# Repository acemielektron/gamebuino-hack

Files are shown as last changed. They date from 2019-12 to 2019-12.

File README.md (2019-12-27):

# gamebuino-hack
A diy clone of open source [gamebuino classic](http://legacy.gamebuino.com/wiki)

**Differences in hardware**
  - Hack is based on Atmega328 PDIP so it does not have A6 and A7 (PC6 and PC7) pins
  - Button C is moved to D5 (PD5) -> rebuilding all games and bootloader needed for this change to work
  - Battery sensor is moved to ADC3 (PC3) -> rebuilding all games are needed for this change to work
  - No ambient light sensor
  - No pwm control for background led

**Bootloader**
  - gamebuino requires a [custom bootloader](https://github.com/ghalfacree/Arduino-Sketches/tree/master/hardware/arduino/bootloaders/gamebuino_boot) for loading games from sd-card to work
  - gamebuino bootloader only supports fat16 formatted sd cards

**Pictures**

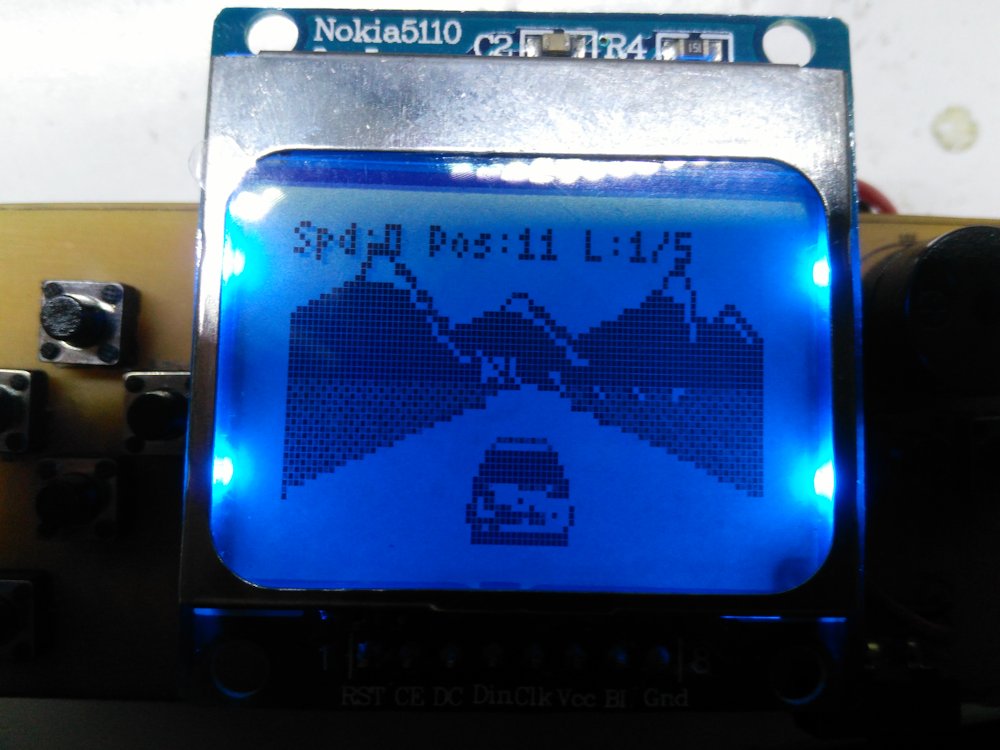
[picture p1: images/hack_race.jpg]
Hack running race


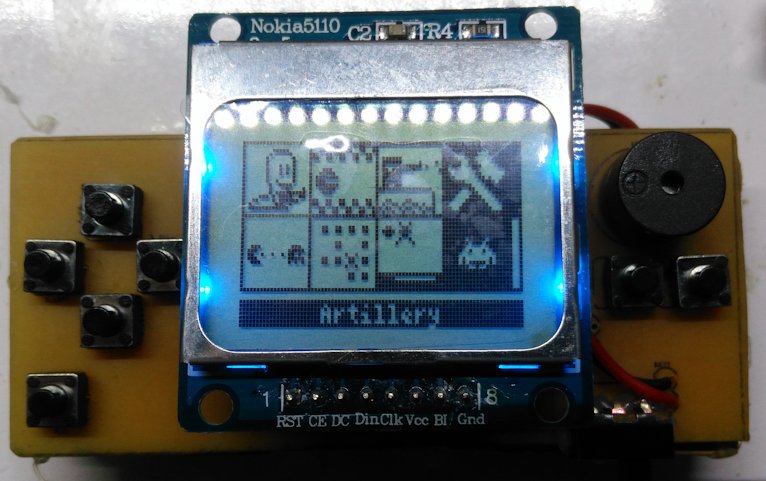
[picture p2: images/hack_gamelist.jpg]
Hack games selection screen


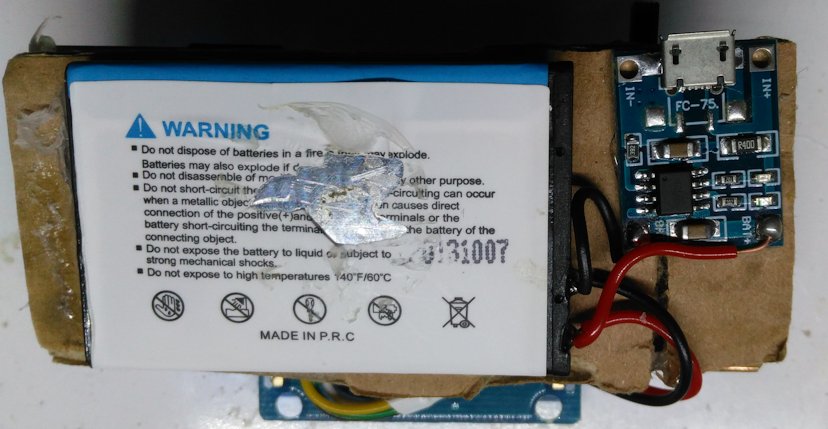
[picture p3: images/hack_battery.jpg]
Hack 850ma Nokia battery & TP4056 charger


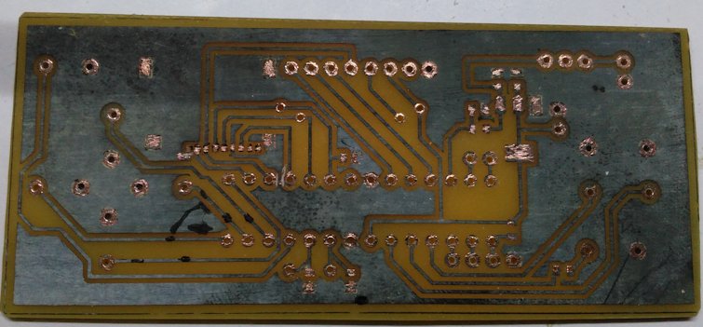
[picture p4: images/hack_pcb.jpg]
Hack PCB backside


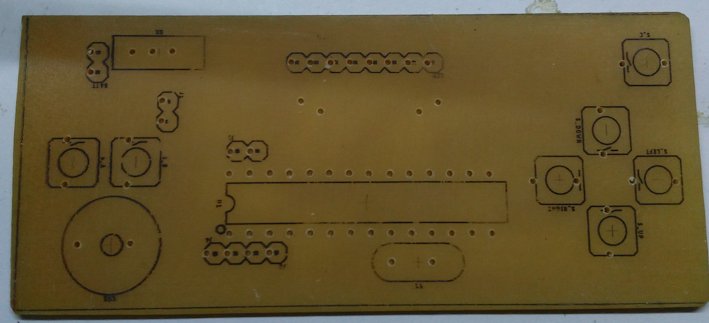
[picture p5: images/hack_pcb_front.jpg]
Hack PCB frontside


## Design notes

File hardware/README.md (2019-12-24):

# gamebuino-hack (eagle cad files)
A diy clone of open source [gamebuino classic](http://legacy.gamebuino.com/wiki)

**Differences in hardware**
  - Hack is based on Atmega328 PDIP so it does not have A6 and A7 (PC6 and PC7) pins
  - Button C is moved to D5 (PD5) -> rebuilding all games and bootloader needed for this change to work
  - Battery sensor is moved to ADC3 (PC3) -> rebuilding all games are needed for this change to work
  - No ambient light sensor
  - No pwm control for background led

**Bootloader**
  - gamebuino requires a [custom bootloader](https://github.com/ghalfacree/Arduino-Sketches/tree/master/hardware/arduino/bootloaders/gamebuino_boot) for loading games from sd-card to work
  - gamebuino bootloader only supports fat16 formatted sd cards

**Schematic**
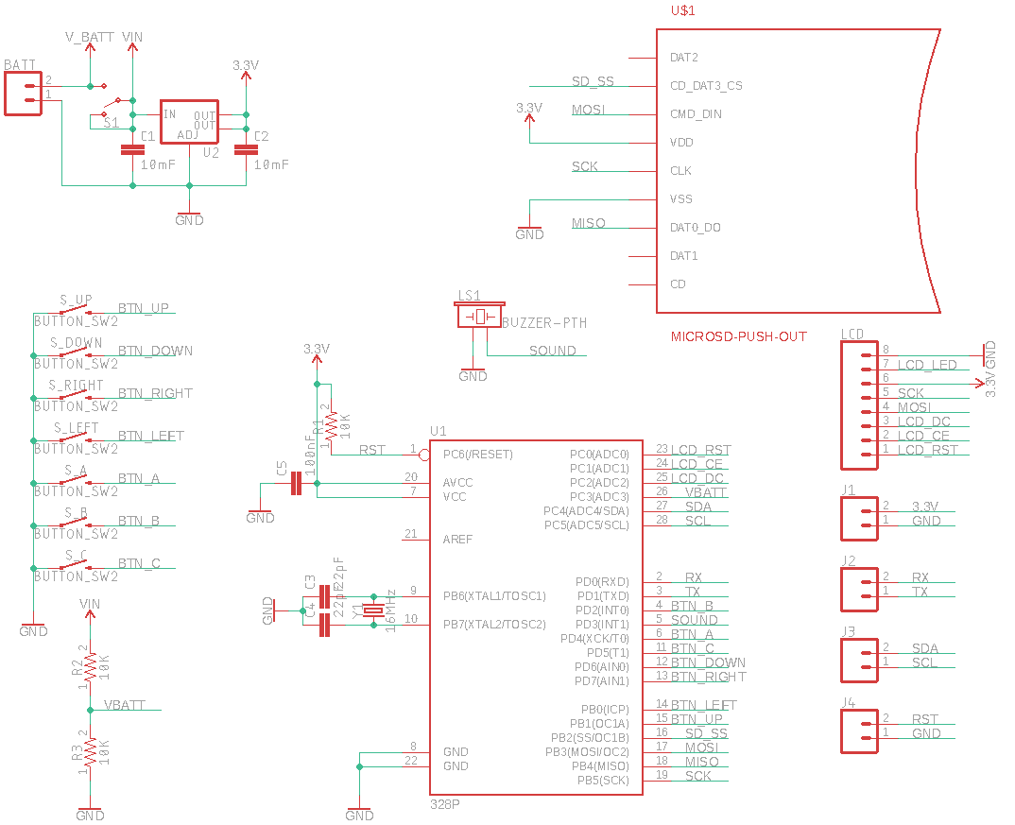
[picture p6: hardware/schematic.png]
Shematic


**PCB**
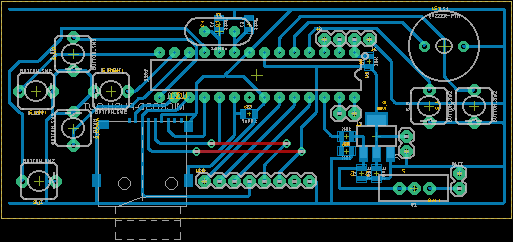
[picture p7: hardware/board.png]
PCB


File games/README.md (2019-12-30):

# gamebuino-hack / games4hack
A diy clone of open source [gamebuino classic](http://legacy.gamebuino.com/wiki)

**Gamebuino games modified for hack**
  - None of these games are written by me, they belong to their respective authors
  - Games with open source are recompiled using arduino ide (v1.8.10) for hack
  - Recompiled B-RALLY (buino-rally) didn't work, so original hex file was disassembled and modified to work on hack.

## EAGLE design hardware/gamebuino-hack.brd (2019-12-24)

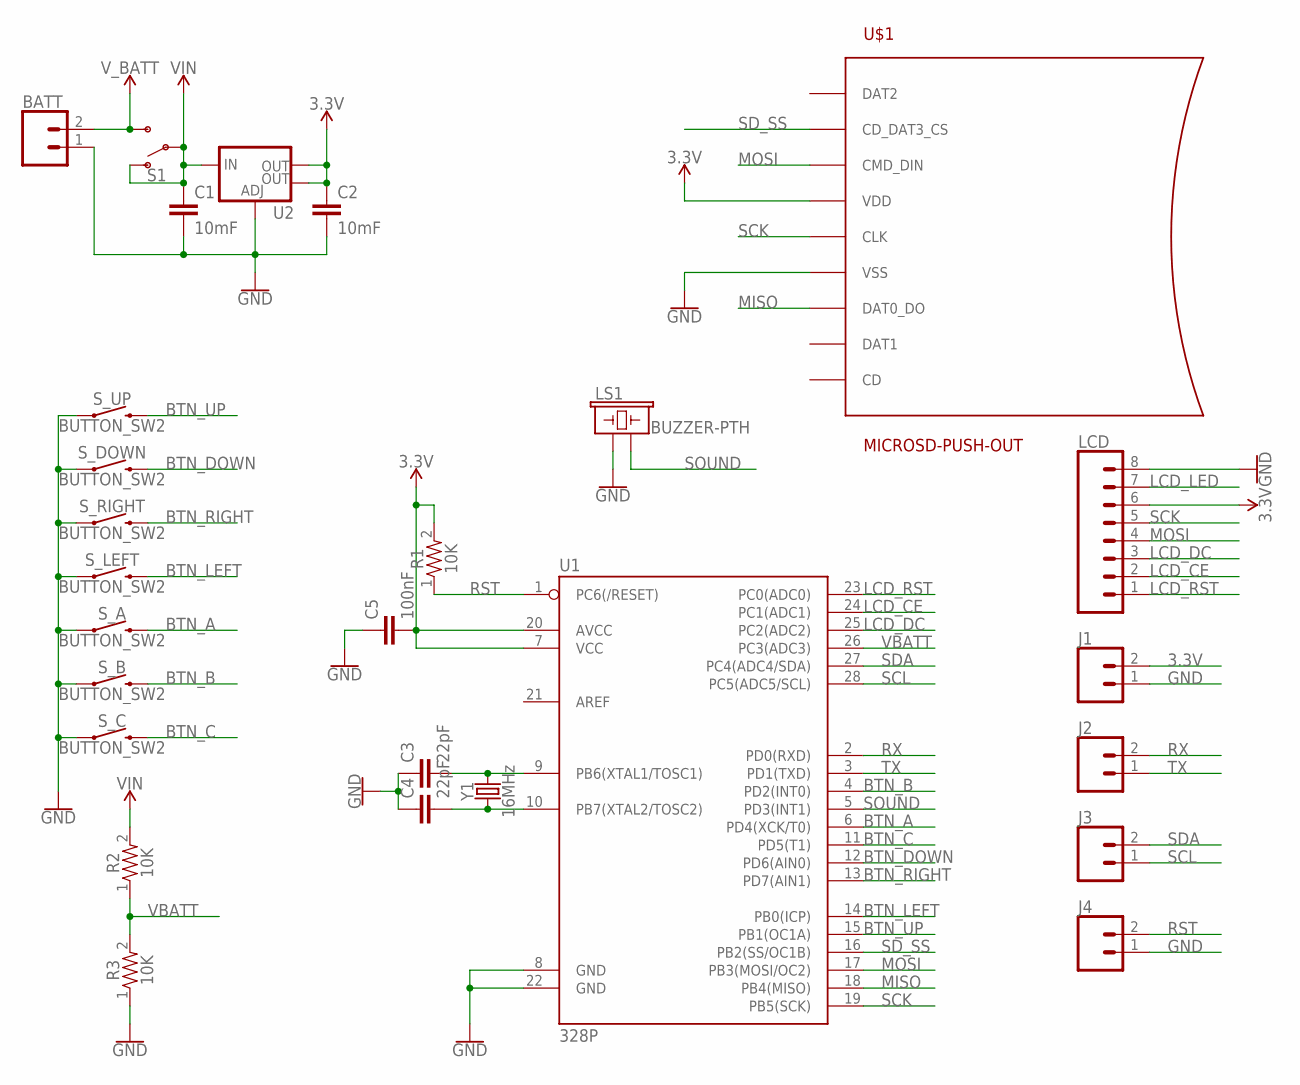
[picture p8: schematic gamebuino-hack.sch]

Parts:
BATT: CONN_02; 1X02
C1, C2: 10mF; 0805
C3, C4: 22pF; 0805
C5: 100nF; 0805
J1, J2, J3, J4: CONN_02; 1X02
LCD: CONN_08"; 1X08
LS1: BUZZER-PTH; BUZZER-12MM
R1, R2, R3: 10K; 0805
S1: SWITCH-SPDT-PTH-11.6X4.0MM; SWITCH_SPDT_PTH_11.6X4.0MM
S_A: BUTTON_SW2
S_B: BUTTON_SW2
S_C: BUTTON_SW2
S_DOWN: BUTTON_SW2
S_LEFT: BUTTON_SW2
S_RIGHT: BUTTON_SW2
S_UP: BUTTON_SW2
U1: 328P; DIP28
U2: V_REG_LM1117SOT223; SOT223
U$1: MICROSD-PUSH-OUT
Y1: 16MHz; HC49US

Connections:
3.3V: C2.1, C5.2, J1.2, LCD.6, R1.2, U1.7 (VCC), U1.20 (AVCC), U2.2 (OUT), U2.4 (OUT), U$1.4 (VDD)
BTN_A: S_A.2, U1.6 (PD4(XCK/T0))
BTN_B: S_B.2, U1.4 (PD2(INT0))
BTN_C: S_C.2, U1.11 (PD5(T1))
BTN_DOWN: S_DOWN.2, U1.12 (PD6(AIN0))
BTN_LEFT: S_LEFT.2, U1.14 (PB0(ICP))
BTN_RIGHT: S_RIGHT.2, U1.13 (PD7(AIN1))
BTN_UP: S_UP.2, U1.15 (PB1(OC1A))
GND: BATT.1, C1.2, C2.2, C3.1, C4.1, C5.1, J1.1, J4.1, LCD.8, LS1.+ (1), R3.1, S_A.1, S_B.1, S_C.1, S_DOWN.1, S_LEFT.1, S_RIGHT.1, S_UP.1, U1.8 (GND), U1.22 (GND), U2.1 (ADJ), U$1.6 (VSS), U$1.G1 (VSS), U$1.G2 (VSS), U$1.G3 (VSS), U$1.G4 (VSS)
LCD_CE: LCD.2, U1.24 (PC1(ADC1))
LCD_DC: LCD.3, U1.25 (PC2(ADC2))
LCD_LED: LCD.7
LCD_RST: LCD.1, U1.23 (PC0(ADC0))
MISO: U1.18 (PB4(MISO)), U$1.7 (DAT0_DO)
MOSI: LCD.4, U1.17 (PB3(MOSI/OC2)), U$1.3 (CMD_DIN)
unnamed: C3.2, U1.9 (PB6(XTAL1/TOSC1)), Y1.2
unnamed: C4.2, U1.10 (PB7(XTAL2/TOSC2)), Y1.1
RST: J4.2, R1.1, U1.1 (PC6(/RESET))
RX: J2.2, U1.2 (PD0(RXD))
SCK: LCD.5, U1.19 (PB5(SCK)), U$1.5 (CLK)
SCL: J3.1, U1.28 (PC5(ADC5/SCL))
SDA: J3.2, U1.27 (PC4(ADC4/SDA))
SD_SS: U1.16 (PB2(SS/OC1B)), U$1.2 (CD_DAT3_CS)
SOUND: LS1.- (2), U1.5 (PD3(INT1))
TX: J2.1, U1.3 (PD1(TXD))
VBATT: R2.1, R3.2, U1.26 (PC3(ADC3))
VIN: C1.1, R2.2, S1.1 (O), S1.2, U2.3 (IN)
V_BATT: BATT.2, S1.3 (S)

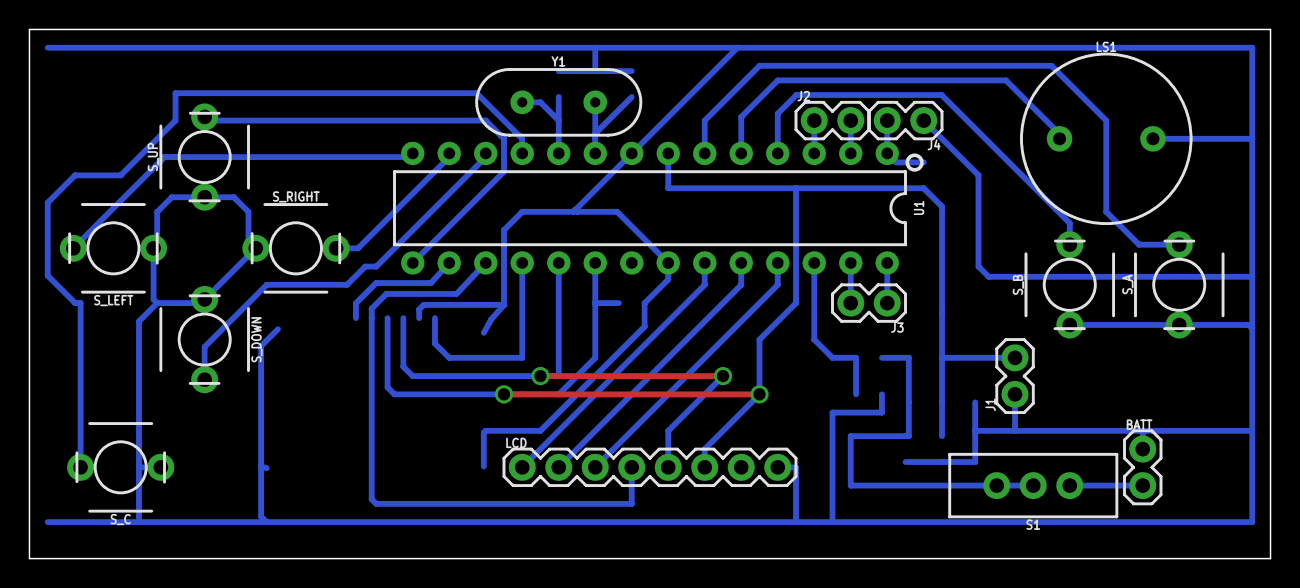
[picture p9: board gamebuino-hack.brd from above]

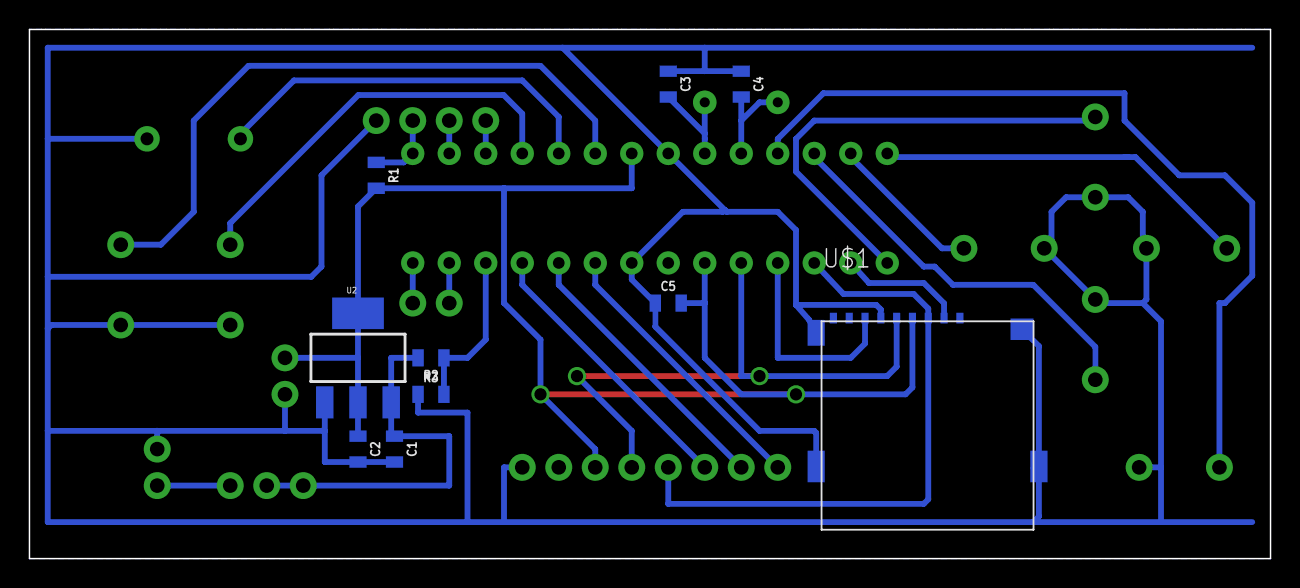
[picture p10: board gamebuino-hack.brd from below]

Board: 2 copper layers, 86.4 x 36.8 mm, 27 parts (10 on the bottom side), 27 nets.

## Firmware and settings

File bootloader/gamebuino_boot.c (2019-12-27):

/**********************************************************/
/* Optiboot bootloader for Arduino                        */
/*                                                        */
/* http://optiboot.googlecode.com                         */
/*                                                        */
/* Arduino-maintained version : See README.TXT            */
/* http://code.google.com/p/arduino/                      */
/*                                                        */
/* Heavily optimised bootloader that is faster and        */
/* smaller than the Arduino standard bootloader           */
/*                                                        */
/* Enhancements:                                          */
/*   Fits in 512 bytes, saving 1.5K of code space         */
/*   Background page erasing speeds up programming        */
/*   Higher baud rate speeds up programming               */
/*   Written almost entirely in C                         */
/*   Customisable timeout with accurate timeconstant      */
/*   Optional virtual UART. No hardware UART required.    */
/*   Optional virtual boot partition for devices without. */
/*                                                        */
/* What you lose:                                         */
/*   Implements a skeleton STK500 protocol which is       */
/*     missing several features including EEPROM          */
/*     programming and non-page-aligned writes            */
/*   High baud rate breaks compatibility with standard    */
/*     Arduino flash settings                             */
/*                                                        */
/* Fully supported:                                       */
/*   ATmega168 based devices  (Diecimila etc)             */
/*   ATmega328P based devices (Duemilanove etc)           */
/*                                                        */
/* Alpha test                                             */
/*   ATmega1280 based devices (Arduino Mega)              */
/*                                                        */
/* Work in progress:                                      */
/*   ATmega644P based devices (Sanguino)                  */
/*   ATtiny84 based devices (Luminet)                     */
/*                                                        */
/* Does not support:                                      */
/*   USB based devices (eg. Teensy)                       */
/*                                                        */
/* Assumptions:                                           */
/*   The code makes several assumptions that reduce the   */
/*   code size. They are all true after a hardware reset, */
/*   but may not be true if the bootloader is called by   */
/*   other means or on other hardware.                    */
/*     No interrupts can occur                            */
/*     UART and Timer 1 are set to their reset state      */
/*     SP points to RAMEND                                */
/*                                                        */
/* Code builds on code, libraries and optimisations from: */
/*   stk500boot.c          by Jason P. Kyle               */
/*   Arduino bootloader    http://arduino.cc              */
/*   Spiff's 1K bootloader http://spiffie.org/know/arduino_1k_bootloader/bootloader.shtml */
/*   avr-libc project      http://nongnu.org/avr-libc     */
/*   Adaboot               http://www.ladyada.net/library/arduino/bootloader.html */
/*   AVR305                Atmel Application Note         */
/*                                                        */
/* This program is free software; you can redistribute it */
/* and/or modify it under the terms of the GNU General    */
/* Public License as published by the Free Software       */
/* Foundation; either version 2 of the License, or        */
/* (at your option) any later version.                    */
/*                                                        */
/* This program is distributed in the hope that it will   */
/* be useful, but WITHOUT ANY WARRANTY; without even the  */
/* implied warranty of MERCHANTABILITY or FITNESS FOR A   */
/* PARTICULAR PURPOSE.  See the GNU General Public        */
/* License for more details.                              */
/*                                                        */
/* You should have received a copy of the GNU General     */
/* Public License along with this program; if not, write  */
/* to the Free Software Foundation, Inc.,                 */
/* 59 Temple Place, Suite 330, Boston, MA  02111-1307 USA */
/*                                                        */
/* Licence can be viewed at                               */
/* http://www.fsf.org/licenses/gpl.txt                    */
/*                                                        */
/**********************************************************/


/**********************************************************/
/*                                                        */
/* Optional defines:                                      */
/*                                                        */
/**********************************************************/
/*                                                        */
/* BIG_BOOT:                                              */
/* Build a 1k bootloader, not 512 bytes. This turns on    */
/* extra functionality.                                   */
/*                                                        */
/* BAUD_RATE:                                             */
/* Set bootloader baud rate.                              */
/*                                                        */
/* LUDICROUS_SPEED:                                       */
/* 230400 baud :-)                                        */
/*                                                        */
/* SOFT_UART:                                             */
/* Use AVR305 soft-UART instead of hardware UART.         */
/*                                                        */
/* LED_START_FLASHES:                                     */
/* Number of LED flashes on bootup.                       */
/*                                                        */
/* LED_DATA_FLASH:                                        */
/* Flash LED when transferring data. For boards without   */
/* TX or RX LEDs, or for people who like blinky lights.   */
/*                                                        */
/* SUPPORT_EEPROM:                                        */
/* Support reading and writing from EEPROM. This is not   */
/* used by Arduino, so off by default.                    */
/*                                                        */
/* TIMEOUT_MS:                                            */
/* Bootloader timeout period, in milliseconds.            */
/* 500,1000,2000,4000,8000 supported.                     */
/*                                                        */
/**********************************************************/

/**********************************************************/
/* Version Numbers!                                       */
/*                                                        */
/* Arduino Optiboot now includes this Version number in   */
/* the source and object code.                            */
/*                                                        */
/* Version 3 was released as zip from the optiboot        */
/*  repository and was distributed with Arduino 0022.     */
/* Version 4 starts with the arduino repository commit    */
/*  that brought the arduino repository up-to-date with   */
/* the optiboot source tree changes since v3.             */
/*                                                        */
/**********************************************************/

/**********************************************************/
/* Edit History:					  */
/*							  */
/* 4.4 WestfW: add initialization of address to keep      */
/*             the compiler happy.  Change SC'ed targets. */
/*             Return the SW version via READ PARAM       */
/* 4.3 WestfW: catch framing errors in getch(), so that   */
/*             AVRISP works without HW kludges.           */
/*  http://code.google.com/p/arduino/issues/detail?id=368n*/
/* 4.2 WestfW: reduce code size, fix timeouts, change     */
/*             verifySpace to use WDT instead of appstart */
/* 4.1 WestfW: put version number in binary.		  */
/**********************************************************/

#define OPTIBOOT_MAJVER 4
#define OPTIBOOT_MINVER 4

#define MAKESTR(a) #a
#define MAKEVER(a, b) MAKESTR(a*256+b)


asm("  .section .version\n"
    "optiboot_version:  .word " MAKEVER(OPTIBOOT_MAJVER, OPTIBOOT_MINVER) "\n"
    "  .section .text\n");

asm(	".section .jumps,\"ax\",@progbits\n"
		".global _jumptable\n"
		"_jumptable:\n"
		"rjmp write_flash_page\n"
		"rjmp load_game\n"
		".section .text\n");

#include <inttypes.h>
#include <avr/io.h>
#include <avr/pgmspace.h>
#include <util/delay.h>

// <avr/boot.h> uses sts instructions, but this version uses out instructions
// This saves cycles and program memory.
#include "boot.h"
#include <string.h>
#include "prog_flash.h"


// We don't use <avr/wdt.h> as those routines have interrupt overhead we don't need.

#include "pin_defs.h"
#include "stk500.h"
#include "mmc_fat.h"

#ifndef LED_START_FLASHES
#define LED_START_FLASHES 3
#endif

#ifdef LUDICROUS_SPEED
#define BAUD_RATE 230400L
#endif

/* set the UART baud rate defaults */
#ifndef BAUD_RATE
#if F_CPU >= 8000000L
#define BAUD_RATE   115200L // Highest rate Avrdude win32 will support
#elsif F_CPU >= 1000000L
#define BAUD_RATE   9600L   // 19200 also supported, but with significant error
#elsif F_CPU >= 128000L
#define BAUD_RATE   4800L   // Good for 128kHz internal RC
#else
#define BAUD_RATE 1200L     // Good even at 32768Hz
#endif
#endif

/* Switch in soft UART for hard baud rates */
#if (F_CPU/BAUD_RATE) > 280 // > 57600 for 16MHz
#ifndef SOFT_UART
#define SOFT_UART
#endif
#endif

/* Watchdog settings */
#define WATCHDOG_OFF    (0)
#define WATCHDOG_16MS   (_BV(WDE))
#define WATCHDOG_32MS   (_BV(WDP0) | _BV(WDE))
#define WATCHDOG_64MS   (_BV(WDP1) | _BV(WDE))
#define WATCHDOG_125MS  (_BV(WDP1) | _BV(WDP0) | _BV(WDE))
#define WATCHDOG_250MS  (_BV(WDP2) | _BV(WDE))
#define WATCHDOG_500MS  (_BV(WDP2) | _BV(WDP0) | _BV(WDE))
#define WATCHDOG_1S     (_BV(WDP2) | _BV(WDP1) | _BV(WDE))
#define WATCHDOG_2S     (_BV(WDP2) | _BV(WDP1) | _BV(WDP0) | _BV(WDE))
#ifndef __AVR_ATmega8__
#define WATCHDOG_4S     (_BV(WDP3) | _BV(WDE))
#define WATCHDOG_8S     (_BV(WDP3) | _BV(WDP0) | _BV(WDE))
#endif

/* Function Prototypes */
/* The main function is in init9, which removes the interrupt vector table */
/* we don't need. It is also 'naked', which means the compiler does not    */
/* generate any entry or exit code itself. */
int main(void) __attribute__ ((naked)) __attribute__ ((section (".init9")));
void putch(char);
//void putstring(char * str);
uint8_t getch(void);
static inline void getNch(uint8_t); /* "static inline" is a compiler hint to reduce code size */
void verifySpace();
static inline void flash_led(uint8_t);
uint8_t getLen();
static inline void watchdogReset();
void watchdogConfig(uint8_t x);
static inline void reboot();
void load_loader();
void load_game(const char * filename);

#ifdef SOFT_UART
void uartDelay() __attribute__ ((naked));
#endif
void appStart() __attribute__ ((naked));

#if defined(__AVR_ATmega168__)
#define RAMSTART (0x100)
#define NRWWSTART (0x3800)
#elif defined(__AVR_ATmega328P__)
#define RAMSTART (0x100)
#define NRWWSTART (0x7000)
#elif defined (__AVR_ATmega644P__)
#define RAMSTART (0x100)
#define NRWWSTART (0xE000)
#elif defined(__AVR_ATtiny84__)
#define RAMSTART (0x100)
#define NRWWSTART (0x0000)
#elif defined(__AVR_ATmega1280__)
#define RAMSTART (0x200)
#define NRWWSTART (0xE000)
#elif defined(__AVR_ATmega8__) || defined(__AVR_ATmega88__)
#define RAMSTART (0x100)
#define NRWWSTART (0x1800)
#endif

/* C zero initialises all global variables. However, that requires */
/* These definitions are NOT zero initialised, but that doesn't matter */
/* This allows us to drop the zero init code, saving us memory */
#define buff    ((uint8_t*)(RAMSTART))
#ifdef VIRTUAL_BOOT_PARTITION
#define rstVect (*(uint16_t*)(RAMSTART+SPM_PAGESIZE*2+4))
#define wdtVect (*(uint16_t*)(RAMSTART+SPM_PAGESIZE*2+6))
#endif

/* main program starts here */
int main(void) {
  uint8_t ch;

  /*
   * Making these local and in registers prevents the need for initializing
   * them, and also saves space because code no longer stores to memory.
   * (initializing address keeps the compiler happy, but isn't really
   *  necessary, and uses 4 bytes of flash.)
   */
  register uint16_t address = 0;
  register uint8_t  length;

  // After the zero init loop, this is the first code to run.
  //
  // This code makes the following assumptions:
  //  No interrupts will execute
  //  SP points to RAMEND
  //  r1 contains zero
  //
  // If not, uncomment the following instructions:
  // cli();
  asm volatile ("clr __zero_reg__");
#ifdef __AVR_ATmega8__
  SP=RAMEND;  // This is done by hardware reset
#endif

  // if the D5 button is currently pressed then try to run the loader app
  DDRD &= ~(1 << PD5);
  PORTD |= (1 << PD5);
  _delay_ms(1); //wait for parasitic capacitance
  if (!(PIND & (1<<PD5)))
	  load_loader();

  // Adaboot no-wait mod
  ch = MCUSR;
  MCUSR = 0;
  if (!(ch & _BV(EXTRF))) appStart();

#if LED_START_FLASHES > 0
  // Set up Timer 1 for timeout counter
  TCCR1B = _BV(CS12) | _BV(CS10); // div 1024
#endif
#ifndef SOFT_UART
#ifdef __AVR_ATmega8__
  UCSRA = _BV(U2X); //Double speed mode USART
  UCSRB = _BV(RXEN) | _BV(TXEN);  // enable Rx & Tx
  UCSRC = _BV(URSEL) | _BV(UCSZ1) | _BV(UCSZ0);  // config USART; 8N1
  UBRRL = (uint8_t)( (F_CPU + BAUD_RATE * 4L) / (BAUD_RATE * 8L) - 1 );
#else
  UCSR0A = _BV(U2X0); //Double speed mode USART0
  UCSR0B = _BV(RXEN0) | _BV(TXEN0);
  UCSR0C = _BV(UCSZ00) | _BV(UCSZ01);
  UBRR0L = (uint8_t)( (F_CPU + BAUD_RATE * 4L) / (BAUD_RATE * 8L) - 1 );
#endif
#endif

  // Set up watchdog to trigger after 500ms
  watchdogConfig(WATCHDOG_1S);

  /* Set LED pin as output */
  //LED_DDR |= _BV(LED);

#ifdef SOFT_UART
  /* Set TX pin as output */
  //UART_DDR |= _BV(UART_TX_BIT);
#endif

#if LED_START_FLASHES > 0
  /* Flash onboard LED to signal entering of bootloader */
  flash_led(LED_START_FLASHES * 2);
#endif


  /* Forever loop */
  for (;;) {
    /* get character from UART */
    ch = getch();

    if(ch == STK_GET_PARAMETER) {
      unsigned char which = getch();
      verifySpace();
      if (which == 0x82) {
	/*
	 * Send optiboot version as "minor SW version"
	 */
	putch(OPTIBOOT_MINVER);
      } else if (which == 0x81) {
	  putch(OPTIBOOT_MAJVER);
      } else {
	/*
	 * GET PARAMETER returns a generic 0x03 reply for
         * other parameters - enough to keep Avrdude happy
	 */
	putch(0x03);
      }
    }
    else if(ch == STK_SET_DEVICE) {
      // SET DEVICE is ignored
      getNch(20);
    }
    else if(ch == STK_SET_DEVICE_EXT) {
      // SET DEVICE EXT is ignored
      getNch(5);
    }
    else if(ch == STK_LOAD_ADDRESS) {
      // LOAD ADDRESS
      uint16_t newAddress;
      newAddress = getch();
      newAddress = (newAddress & 0xff) | (getch() << 8);
#ifdef RAMPZ
      // Transfer top bit to RAMPZ
      RAMPZ = (newAddress & 0x8000) ? 1 : 0;
#endif
      newAddress += newAddress; // Convert from word address to byte address
      address = newAddress;
      verifySpace();
    }
    else if(ch == STK_UNIVERSAL) {
      // UNIVERSAL command is ignored
      getNch(4);
      putch(0x00);
    }
    /* Write memory, length is big endian and is in bytes */
    else if(ch == STK_PROG_PAGE) {
      // PROGRAM PAGE - we support flash programming only, not EEPROM
      uint8_t *bufPtr;
      //uint16_t addrPtr;

      getch();			/* getlen() */
      length = getch();
      getch();

	  // the original optiboot code erases memory before reading in the contents. this is faster but takes up more memory so I've taken it out.

      // read in page contents
      bufPtr = pagebuffer;
      do *bufPtr++ = getch();
      while (--length);

      // Read command terminator, start reply
      verifySpace();

	  // flash the chip
	  write_pagebuffer((uint16_t)(void*)address);
    }

    /* Read memory block mode, length is big endian.  */
    else if(ch == STK_READ_PAGE) {
      // READ PAGE - we only read flash
      getch();			/* getlen() */
      length = getch();
      getch();

      verifySpace();
#ifdef VIRTUAL_BOOT_PARTITION
      do {
        // Undo vector patch in bottom page so verify passes
        if (address == 0)       ch=rstVect & 0xff;
        else if (address == 1)  ch=rstVect >> 8;
        else if (address == 8)  ch=wdtVect & 0xff;
        else if (address == 9) ch=wdtVect >> 8;
        else ch = pgm_read_byte_near(address);
        address++;
        putch(ch);
      } while (--length);
#else
#ifdef __AVR_ATmega1280__
//      do putch(pgm_read_byte_near(address++));
//      while (--length);
      do {
        uint8_t result;
        __asm__ ("elpm %0,Z\n":"=r"(result):"z"(address));
        putch(result);
        address++;
      }
      while (--length);
#else
      do putch(pgm_read_byte_near(address++));
      while (--length);
#endif
#endif
    }

    /* Get device signature bytes  */
    else if(ch == STK_READ_SIGN) {
      // READ SIGN - return what Avrdude wants to hear
      verifySpace();
      putch(SIGNATURE_0);
      putch(SIGNATURE_1);
      putch(SIGNATURE_2);
    }
    else if (ch == 'Q') {
      // Adaboot no-wait mod
      watchdogConfig(WATCHDOG_16MS);
      verifySpace();
    }
    else {
      // This covers the response to commands like STK_ENTER_PROGMODE
      verifySpace();
    }
    putch(STK_OK);
  }
}

void putch(char ch) {
#ifndef SOFT_UART
  while (!(UCSR0A & _BV(UDRE0)));
  UDR0 = ch;
#else
  __asm__ __volatile__ (
    "   com %[ch]\n" // ones complement, carry set
    "   sec\n"
    "1: brcc 2f\n"
    "   cbi %[uartPort],%[uartBit]\n"
    "   rjmp 3f\n"
    "2: sbi %[uartPort],%[uartBit]\n"
    "   nop\n"
    "3: rcall uartDelay\n"
    "   rcall uartDelay\n"
    "   lsr %[ch]\n"
    "   dec %[bitcnt]\n"
    "   brne 1b\n"
    :
    :
      [bitcnt] "d" (10),
      [ch] "r" (ch),
      [uartPort] "I" (_SFR_IO_ADDR(UART_PORT)),
      [uartBit] "I" (UART_TX_BIT)
    :
      "r25"
  );
#endif
}

void putstring(char * str)
{
	while (*str)
		putch(*str++);
}

uint8_t getch(void) {
  uint8_t ch;

#ifdef LED_DATA_FLASH
#ifdef __AVR_ATmega8__
  LED_PORT ^= _BV(LED);
#else
  LED_PIN |= _BV(LED);
#endif
#endif

#ifdef SOFT_UART
  __asm__ __volatile__ (
    "1: sbic  %[uartPin],%[uartBit]\n"  // Wait for start edge
    "   rjmp  1b\n"
    "   rcall uartDelay\n"          // Get to middle of start bit
    "2: rcall uartDelay\n"              // Wait 1 bit period
    "   rcall uartDelay\n"              // Wait 1 bit period
    "   clc\n"
    "   sbic  %[uartPin],%[uartBit]\n"
    "   sec\n"
    "   dec   %[bitCnt]\n"
    "   breq  3f\n"
    "   ror   %[ch]\n"
    "   rjmp  2b\n"
    "3:\n"
    :
      [ch] "=r" (ch)
    :
      [bitCnt] "d" (9),
      [uartPin] "I" (_SFR_IO_ADDR(UART_PIN)),
      [uartBit] "I" (UART_RX_BIT)
    :
      "r25"
);
#else
  while(!(UCSR0A & _BV(RXC0)))
    ;
  if (!(UCSR0A & _BV(FE0))) {
      /*
       * A Framing Error indicates (probably) that something is talking
       * to us at the wrong bit rate.  Assume that this is because it
       * expects to be talking to the application, and DON'T reset the
       * watchdog.  This should cause the bootloader to abort and run
       * the application "soon", if it keeps happening.  (Note that we
       * don't care that an invalid char is returned...)
       */
    watchdogReset();
  }
  
  ch = UDR0;
#endif

#ifdef LED_DATA_FLASH
#ifdef __AVR_ATmega8__
  LED_PORT ^= _BV(LED);
#else
  LED_PIN |= _BV(LED);
#endif
#endif

  return ch;
}

#ifdef SOFT_UART
// AVR350 equation: #define UART_B_VALUE (((F_CPU/BAUD_RATE)-23)/6)
// Adding 3 to numerator simulates nearest rounding for more accurate baud rates
#define UART_B_VALUE (((F_CPU/BAUD_RATE)-20)/6)
#if UART_B_VALUE > 255
#error Baud rate too slow for soft UART
#endif

void uartDelay() {
  __asm__ __volatile__ (
    "ldi r25,%[count]\n"
    "1:dec r25\n"
    "brne 1b\n"
    "ret\n"
    ::[count] "M" (UART_B_VALUE)
  );
}
#endif

void getNch(uint8_t count) {
  do getch(); while (--count);
  verifySpace();
}

void verifySpace() {
  if (getch() != CRC_EOP) {
    reboot();
  }
  putch(STK_INSYNC);
}

#if LED_START_FLASHES > 0
void flash_led(uint8_t count) {
  do {
    TCNT1 = -(F_CPU/(1024*16));
    TIFR1 = _BV(TOV1);
    while(!(TIFR1 & _BV(TOV1)));
#ifdef __AVR_ATmega8__
    //LED_PORT ^= _BV(LED);
#else
    //LED_PIN |= _BV(LED);
#endif
    watchdogReset();
  } while (--count);
}
#endif

// Watchdog functions. These are only safe with interrupts turned off.
void watchdogReset() {
  __asm__ __volatile__ (
    "wdr\n"
  );
}

void watchdogConfig(uint8_t x) {
  WDTCSR = _BV(WDCE) | _BV(WDE);
  WDTCSR = x;
}

void appStart() {
  watchdogConfig(WATCHDOG_OFF);
  
  __asm__ __volatile__ (
#ifdef VIRTUAL_BOOT_PARTITION
    // Jump to WDT vector
    "ldi r30,4\n"
    "clr r31\n"
#else
    // Jump to RST vector
    "clr r30\n"
    "clr r31\n"
#endif
    "ijmp\n"
  );
}

void reboot()
{
	watchdogConfig(WATCHDOG_16MS);
	asm("sei");
	while (1);
}

#include <avr/pgmspace.h>

void load_loader()
{
	watchdogConfig(WATCHDOG_OFF);

	// silly, but it works
	static char filename[7];
	filename[0] = 'L';
	filename[1] = 'O';
	filename[2] = 'A';
	filename[3] = 'D';
	filename[4] = 'E';
	filename[5] = 'R';
	filename[6] = 0;
	load_game(filename);
}
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

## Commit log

2019-12-23 eagle files
    [gamebuino-hack.brd, gamebuino-hack.sch]
2019-12-24 Modify bootloader for button C at D5
    [gamebuino-hack.brd, gamebuino-hack.sch]
2019-12-24 Corrected sound output (removed cap)
    [gamebuino-hack.brd, gamebuino-hack.sch]
2019-12-27 Added delay before reading button C Reading button C immediately after setting internal pullup was causing bootlock adding a delay cost additional 12 bytes in bootloader but prevented bootlock.
    [gamebuino_boot.c]
2019-12-30 Add gamebuino-classic arduino library for reference
2019-12-30 Add gamebuino-classic arduino library

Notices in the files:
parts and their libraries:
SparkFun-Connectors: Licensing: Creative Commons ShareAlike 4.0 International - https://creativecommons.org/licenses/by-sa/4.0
